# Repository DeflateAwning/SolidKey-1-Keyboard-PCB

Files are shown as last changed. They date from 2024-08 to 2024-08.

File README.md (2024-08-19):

# SolidKey-1-Keyboard-PCB
A capacitive touch QMK keyboard, with aspirations of replacing the Framework 13 keyboard

## Inspiration

* This project is inspired by [ebastler's UnMechanical Keyboard](https://github.com/ebastler/UnMechanical).

## Goals

* Make a columnar keyboard with a capacitive touch interface.
* Make the keyboard fit between the Framework 13 keyboard space and screen. Be compatible with the Framework 13 input cover's wiring.
* Base the locations of the keys on the Iris 6 keyboard.
* Parts:
    * RP2040 microcontroller
    * USB-C
    * Vibration motor
    * No LEDs!
* Low-ish power, low mass
* <$80 for a fully-assembled keyboard from JLCPCB

## Licence

The hardware component of this project is licenced under the `CERN Open Hardware Licence Version 2 - Weakly Reciprocal` licence. Variations must be shared under the same licence (or equivalent) licence. Commercial use is allowed, but the source must be shared, and it must be released/sold under a different name.

## Notes

* Framework 13 keyboard dimensions: 276.76mm x 105.0mm x 1.74mm, at the bottom of the taper up, based on their full STEP CAD model.
* For the 276mm x 105mm PCB from JLCPCB, it costs:
    * US$16.80 for 0.6mm thick, LeadFree HASL
    * US$60.60 for 0.4mm thick, requiring ENIG
    * US$10 shipping for these thin boards.
    * US$50 for 0.6mm assembly ("Standard"), but US$26 for 0.8mm assembly ("Economic").
    * 0.8mm weighs 54g each. 0.6mm weighs 40g-54g each.

## Resources

* RP2040 Design Guide: https://datasheets.raspberrypi.com/rp2040/hardware-design-with-rp2040.pdf
* CY8CMBR3116 Capacitive Touch Guides:
    * Datasheet: https://www.infineon.com/cms/en/product/microcontroller/sensing-controller/capsense-controllers/capsense-mbr3/cy8cmbr3116-lqxit/
    * CY8CMBR3xxx CapSense Design Guide: https://www.cypress.com/?rID=90800
    * Getting Started with CapSense: https://www.cypress.com/?rID=48787

## Future Work

* Add a dot mouse thing, like the ThinkPad keyboards.

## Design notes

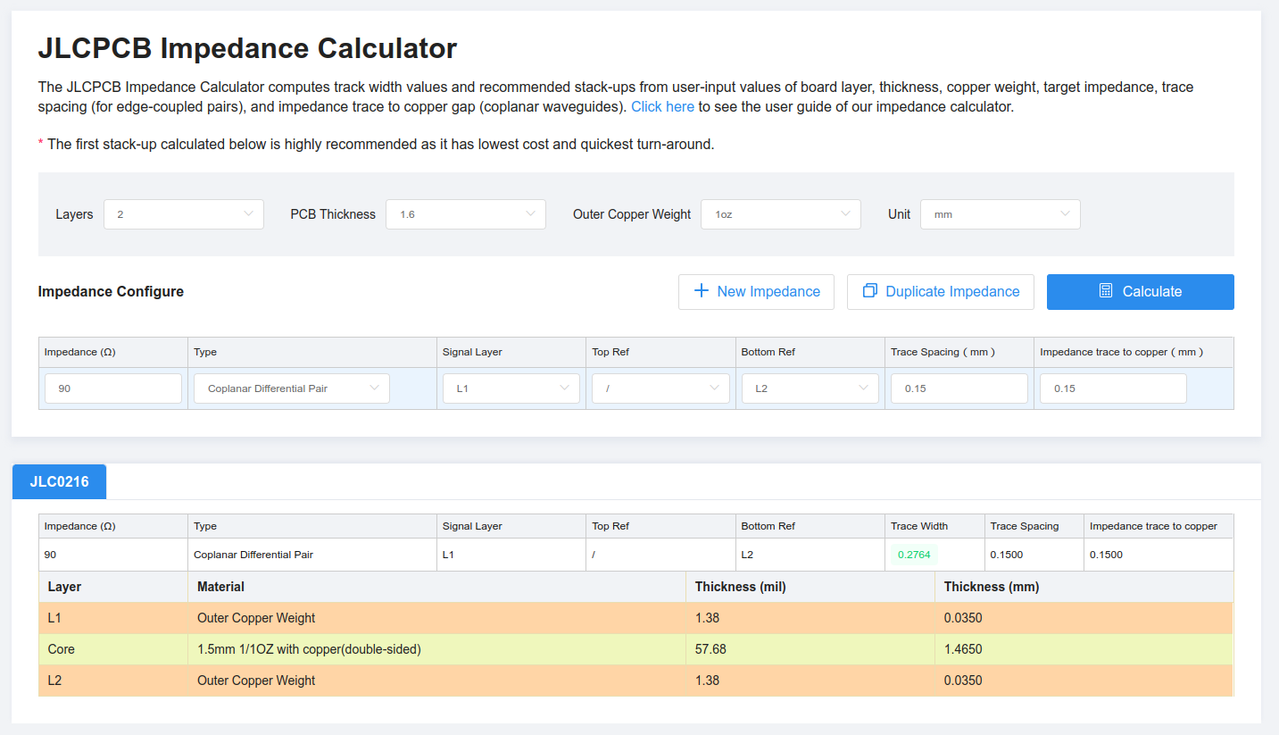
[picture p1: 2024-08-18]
docs/USB Trace Width Calculation - JLCPCB - 2 Layer, 0.15mm Spacing, 1.6mm PCB.png

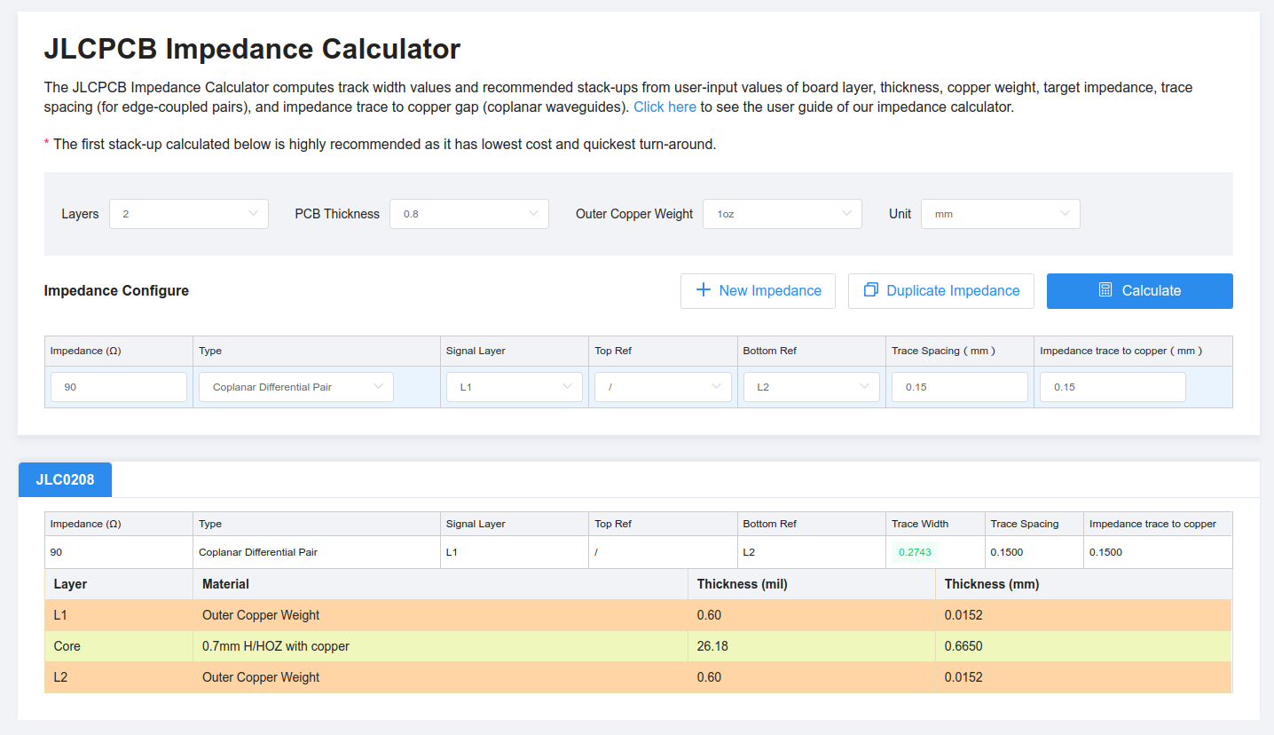
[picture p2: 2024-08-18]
docs/USB Trace Width Calculation - JLCPCB - 2 Layer, 0.15mm Spacing, 0.8mm PCB.png

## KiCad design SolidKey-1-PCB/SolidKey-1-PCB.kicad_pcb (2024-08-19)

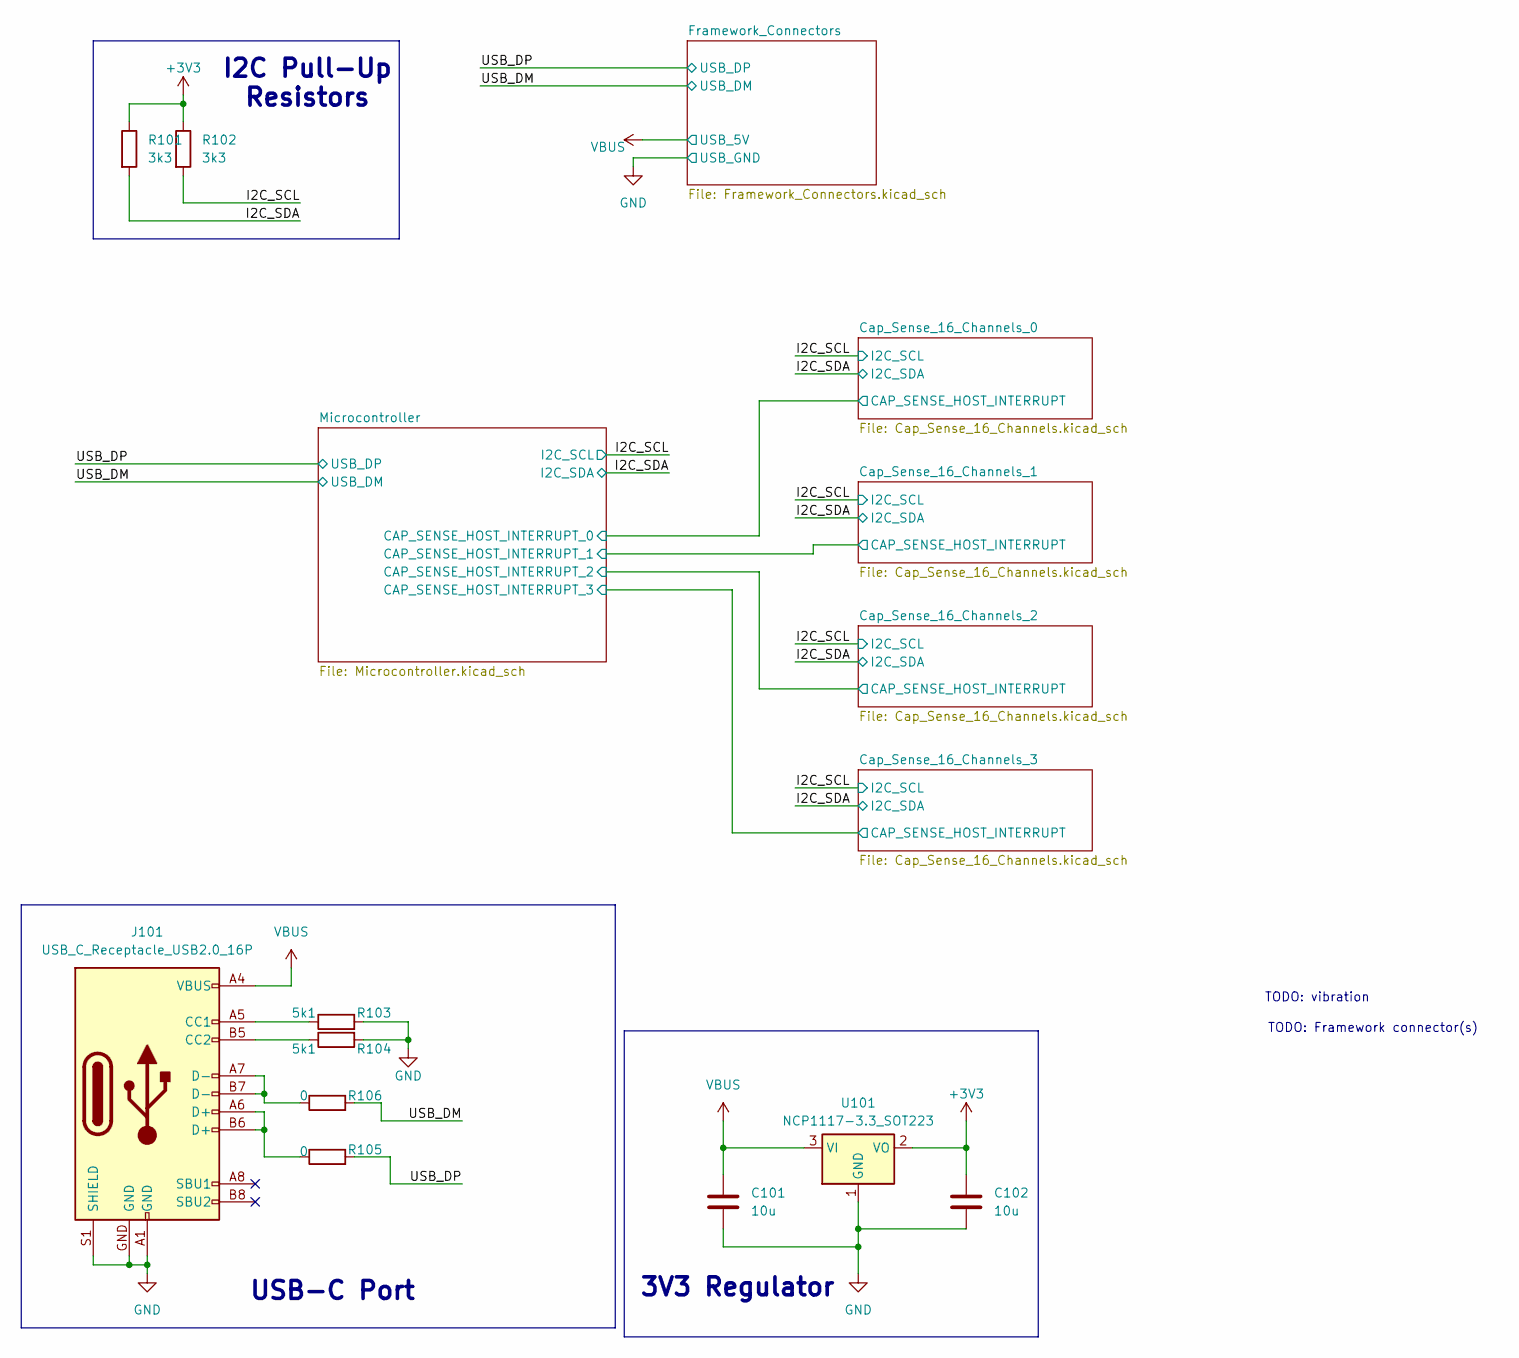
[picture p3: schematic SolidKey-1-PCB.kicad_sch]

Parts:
C101, C102: 10u; C_0402_1005Metric
J101: USB_C_Receptacle_USB2.0_16P; USB_C_Receptacle_G-Switch_GT-USB-7025
R101, R102: 3k3; R_0402_1005Metric
R103, R104: 5k1; R_0402_1005Metric
R105, R106: 0; R_0603_1608Metric
U101: NCP1117-3.3_SOT223; SOT-223-3_TabPin2

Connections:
+3V3: C102.1, R101.1, R102.1, U101.2 (VO); also elsewhere on the board
/I2C_SCL: R102.2; also elsewhere on the board
/I2C_SDA: R101.2; also elsewhere on the board
/USB_DM: R106.2; also elsewhere on the board
/USB_DP: R105.2; also elsewhere on the board
GND: C101.2, C102.2, J101.A1 (GND), J101.A12 (GND), J101.B1 (GND), J101.B12 (GND), J101.GND, J101.S1 (SHIELD), R103.2, R104.2, U101.1 (GND); also elsewhere on the board
unnamed: J101.A5 (CC1), R103.1
unnamed: J101.B5 (CC2), R104.1
unnamed: J101.A6 (D+), J101.B6 (D+), R105.1
unnamed: J101.A7 (D-), J101.B7 (D-), R106.1
VBUS: C101.1, J101.A4 (VBUS), J101.A9 (VBUS), J101.B4 (VBUS), J101.B9 (VBUS), U101.3 (VI); also elsewhere on the board

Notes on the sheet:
3V3 Regulator
I2C Pull-Up Resistors
TODO: Framework connector(s)
USB-C Port
TODO: vibration

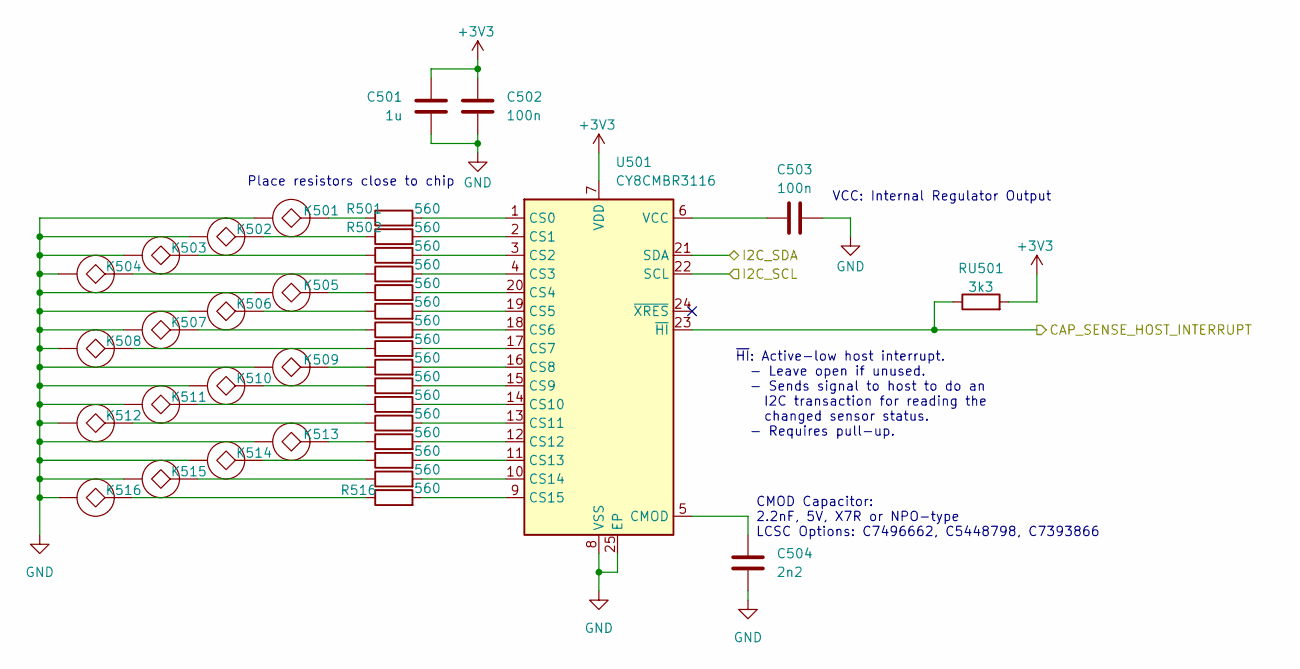
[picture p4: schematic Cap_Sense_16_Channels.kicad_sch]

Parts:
C501: 1u; C_0402_1005Metric
C502, C503: 100n; C_0402_1005Metric
C504: 2n2; C_0402_1005Metric; LCSC C7393866
K501, K502, K503, K504, K505, K506, K507, K508, K510, K511, K512, K514, K515, K516: TouchPoint; KeySwitch1_General
K509, K513: TouchPoint; KeySwitch1_Index
R501, R502, R503, R504, R505, R506, R507, R508, R509, R510, R511, R512, R513, R514, R515, R516: 560; R_0603_1608Metric
RU501: 3k3; R_0402_1005Metric
U501: CY8CMBR3116; QFN-24-1EP_4x4mm_P0.5mm_EP2.6x2.6mm

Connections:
+3V3: C501.1, C502.1, RU501.2, U501.7 (VDD); also elsewhere on the board
/Cap_Sense_16_Channels_2/CAP_SENSE_HOST_INTERRUPT: RU501.1, U501.23 (~HI); also elsewhere on the board
/I2C_SCL: U501.22 (SCL); also elsewhere on the board
/I2C_SDA: U501.21 (SDA); also elsewhere on the board
GND: C501.2, C502.2, C503.2, C504.2, K501.2 (GND), K502.2 (GND), K503.2 (GND), K504.2 (GND), K505.2 (GND), K506.2 (GND), K507.2 (GND), K508.2 (GND), K509.2 (GND), K510.2 (GND), K511.2 (GND), K512.2 (GND), K513.2 (GND), K514.2 (GND), K515.2 (GND), K516.2 (GND), U501.8 (VSS), U501.25 (EP); also elsewhere on the board
unnamed: K501.1, R501.1
unnamed: K502.1, R502.1
unnamed: K503.1, R503.1
unnamed: K504.1, R504.1
unnamed: K505.1, R505.1
unnamed: K506.1, R506.1
unnamed: K507.1, R507.1
unnamed: K508.1, R508.1
unnamed: K509.1, R509.1
unnamed: K510.1, R510.1
unnamed: K511.1, R511.1
unnamed: K512.1, R512.1
unnamed: K513.1, R513.1
unnamed: K514.1, R514.1
unnamed: K515.1, R515.1
unnamed: K516.1, R516.1
unnamed: C504.1, U501.5 (CMOD)
unnamed: R501.2, U501.1 (CS0)
unnamed: R502.2, U501.2 (CS1)
unnamed: R503.2, U501.3 (CS2)
unnamed: R504.2, U501.4 (CS3)
unnamed: R505.2, U501.20 (CS4)
unnamed: R506.2, U501.19 (CS5)
unnamed: R507.2, U501.18 (CS6)
unnamed: R508.2, U501.17 (CS7)
unnamed: R509.2, U501.16 (CS8)
unnamed: R510.2, U501.15 (CS9)
unnamed: R511.2, U501.14 (CS10)
unnamed: R512.2, U501.13 (CS11)
unnamed: R513.2, U501.12 (CS12)
unnamed: R514.2, U501.11 (CS13)
unnamed: R515.2, U501.10 (CS14)
unnamed: R516.2, U501.9 (CS15)
unnamed: C503.1, U501.6 (VCC)

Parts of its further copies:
C301, C401, C601: 1u; C_0402_1005Metric
C302, C303, C402, C403, C602, C603: 100n; C_0402_1005Metric
C304, C404, C604: 2n2; C_0402_1005Metric; LCSC C7393866
K301, K302, K303, K304, K305, K306, K307, K308, K310, K311, K312, K314, K315, K316, K401, K402, K403, K404, K405, K406, K407, K408, K410, K411, K412, K414, K415, K416, K601, K602, K603, K604, K605, K606, K607, K608, K610, K611, K612, K614, K615, K616: TouchPoint; KeySwitch1_General
K309, K313, K409, K413, K609, K613: TouchPoint; KeySwitch1_Index
R301, R302, R303, R304, R305, R306, R307, R308, R309, R310, R311, R312, R313, R314, R315, R316, R401, R402, R403, R404, R405, R406, R407, R408, R409, R410, R411, R412, R413, R414, R415, R416, R601, R602, R603, R604, R605, R606, R607, R608, R609, R610, R611, R612, R613, R614, R615, R616: 560; R_0603_1608Metric
RU301, RU401, RU601: 3k3; R_0402_1005Metric
U301, U401, U601: CY8CMBR3116; QFN-24-1EP_4x4mm_P0.5mm_EP2.6x2.6mm

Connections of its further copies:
+3V3: C301.1, C302.1, C401.1, C402.1, C601.1, C602.1, RU301.2, RU401.2, RU601.2, U301.7 (VDD), U401.7 (VDD), U601.7 (VDD); also elsewhere on the board
/Cap_Sense_16_Channels_0/CAP_SENSE_HOST_INTERRUPT: RU301.1, U301.23 (~HI); also elsewhere on the board
/Cap_Sense_16_Channels_1/CAP_SENSE_HOST_INTERRUPT: RU401.1, U401.23 (~HI); also elsewhere on the board
/Cap_Sense_16_Channels_3/CAP_SENSE_HOST_INTERRUPT: RU601.1, U601.23 (~HI); also elsewhere on the board
/I2C_SCL: U301.22 (SCL), U401.22 (SCL), U601.22 (SCL); also elsewhere on the board
/I2C_SDA: U301.21 (SDA), U401.21 (SDA), U601.21 (SDA); also elsewhere on the board
GND: C301.2, C302.2, C303.2, C304.2, C401.2, C402.2, C403.2, C404.2, C601.2, C602.2, C603.2, C604.2, K301.2 (GND), K302.2 (GND), K303.2 (GND), K304.2 (GND), K305.2 (GND), K306.2 (GND), K307.2 (GND), K308.2 (GND), K309.2 (GND), K310.2 (GND), K311.2 (GND), K312.2 (GND), K313.2 (GND), K314.2 (GND), K315.2 (GND), K316.2 (GND), K401.2 (GND), K402.2 (GND), K403.2 (GND), K404.2 (GND), K405.2 (GND), K406.2 (GND), K407.2 (GND), K408.2 (GND), K409.2 (GND), K410.2 (GND), K411.2 (GND), K412.2 (GND), K413.2 (GND), K414.2 (GND), K415.2 (GND), K416.2 (GND), K601.2 (GND), K602.2 (GND), K603.2 (GND), K604.2 (GND), K605.2 (GND), K606.2 (GND), K607.2 (GND), K608.2 (GND), K609.2 (GND), K610.2 (GND), K611.2 (GND), K612.2 (GND), K613.2 (GND), K614.2 (GND), K615.2 (GND), K616.2 (GND), U301.8 (VSS), U301.25 (EP), U401.8 (VSS), U401.25 (EP), U601.8 (VSS), U601.25 (EP); also elsewhere on the board
unnamed: K301.1, R301.1
unnamed: K302.1, R302.1
unnamed: K303.1, R303.1
unnamed: K304.1, R304.1
unnamed: K305.1, R305.1
unnamed: K306.1, R306.1
unnamed: K307.1, R307.1
unnamed: K308.1, R308.1
unnamed: K309.1, R309.1
unnamed: K310.1, R310.1
unnamed: K311.1, R311.1
unnamed: K312.1, R312.1
unnamed: K313.1, R313.1
unnamed: K314.1, R314.1
unnamed: K315.1, R315.1
unnamed: K316.1, R316.1
unnamed: K401.1, R401.1
unnamed: K402.1, R402.1
unnamed: K403.1, R403.1
unnamed: K404.1, R404.1
unnamed: K405.1, R405.1
unnamed: K406.1, R406.1
unnamed: K407.1, R407.1
unnamed: K408.1, R408.1
unnamed: K409.1, R409.1
unnamed: K410.1, R410.1
unnamed: K411.1, R411.1
unnamed: K412.1, R412.1
unnamed: K413.1, R413.1
unnamed: K414.1, R414.1
unnamed: K415.1, R415.1
unnamed: K416.1, R416.1
unnamed: K601.1, R601.1
unnamed: K602.1, R602.1
unnamed: K603.1, R603.1
unnamed: K604.1, R604.1
unnamed: K605.1, R605.1
unnamed: K606.1, R606.1
unnamed: K607.1, R607.1
unnamed: K608.1, R608.1
unnamed: K609.1, R609.1
unnamed: K610.1, R610.1
unnamed: K611.1, R611.1
unnamed: K612.1, R612.1
unnamed: K613.1, R613.1
unnamed: K614.1, R614.1
unnamed: K615.1, R615.1
unnamed: K616.1, R616.1
unnamed: C304.1, U301.5 (CMOD)
unnamed: R301.2, U301.1 (CS0)
unnamed: R302.2, U301.2 (CS1)
unnamed: R303.2, U301.3 (CS2)
unnamed: R304.2, U301.4 (CS3)
unnamed: R305.2, U301.20 (CS4)
unnamed: R306.2, U301.19 (CS5)
unnamed: R307.2, U301.18 (CS6)
unnamed: R308.2, U301.17 (CS7)
unnamed: R309.2, U301.16 (CS8)
unnamed: R310.2, U301.15 (CS9)
unnamed: R311.2, U301.14 (CS10)
unnamed: R312.2, U301.13 (CS11)
unnamed: R313.2, U301.12 (CS12)
unnamed: R314.2, U301.11 (CS13)
unnamed: R315.2, U301.10 (CS14)
unnamed: R316.2, U301.9 (CS15)
unnamed: C303.1, U301.6 (VCC)
unnamed: C404.1, U401.5 (CMOD)
unnamed: R401.2, U401.1 (CS0)
unnamed: R402.2, U401.2 (CS1)
unnamed: R403.2, U401.3 (CS2)
unnamed: R404.2, U401.4 (CS3)
unnamed: R405.2, U401.20 (CS4)
unnamed: R406.2, U401.19 (CS5)
unnamed: R407.2, U401.18 (CS6)
unnamed: R408.2, U401.17 (CS7)
unnamed: R409.2, U401.16 (CS8)
unnamed: R410.2, U401.15 (CS9)
unnamed: R411.2, U401.14 (CS10)
unnamed: R412.2, U401.13 (CS11)
unnamed: R413.2, U401.12 (CS12)
unnamed: R414.2, U401.11 (CS13)
unnamed: R415.2, U401.10 (CS14)
unnamed: R416.2, U401.9 (CS15)
unnamed: C403.1, U401.6 (VCC)
unnamed: C604.1, U601.5 (CMOD)
unnamed: R601.2, U601.1 (CS0)
unnamed: R602.2, U601.2 (CS1)
unnamed: R603.2, U601.3 (CS2)
unnamed: R604.2, U601.4 (CS3)
unnamed: R605.2, U601.20 (CS4)
unnamed: R606.2, U601.19 (CS5)
unnamed: R607.2, U601.18 (CS6)
unnamed: R608.2, U601.17 (CS7)
unnamed: R609.2, U601.16 (CS8)
unnamed: R610.2, U601.15 (CS9)
unnamed: R611.2, U601.14 (CS10)
unnamed: R612.2, U601.13 (CS11)
unnamed: R613.2, U601.12 (CS12)
unnamed: R614.2, U601.11 (CS13)
unnamed: R615.2, U601.10 (CS14)
unnamed: R616.2, U601.9 (CS15)
unnamed: C603.1, U601.6 (VCC)

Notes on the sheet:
CMOD Capacitor: 2.2nF, 5V, X7R or NPO-type LCSC Options: C7496662, C5448798, C7393866
~{HI}: Active-low host interrupt. - Leave open if unused. - Sends signal to host to do an I2C transaction for reading the changed sensor status. - Requires pull-up.
Place resistors close to chip
VCC: Internal Regulator Output

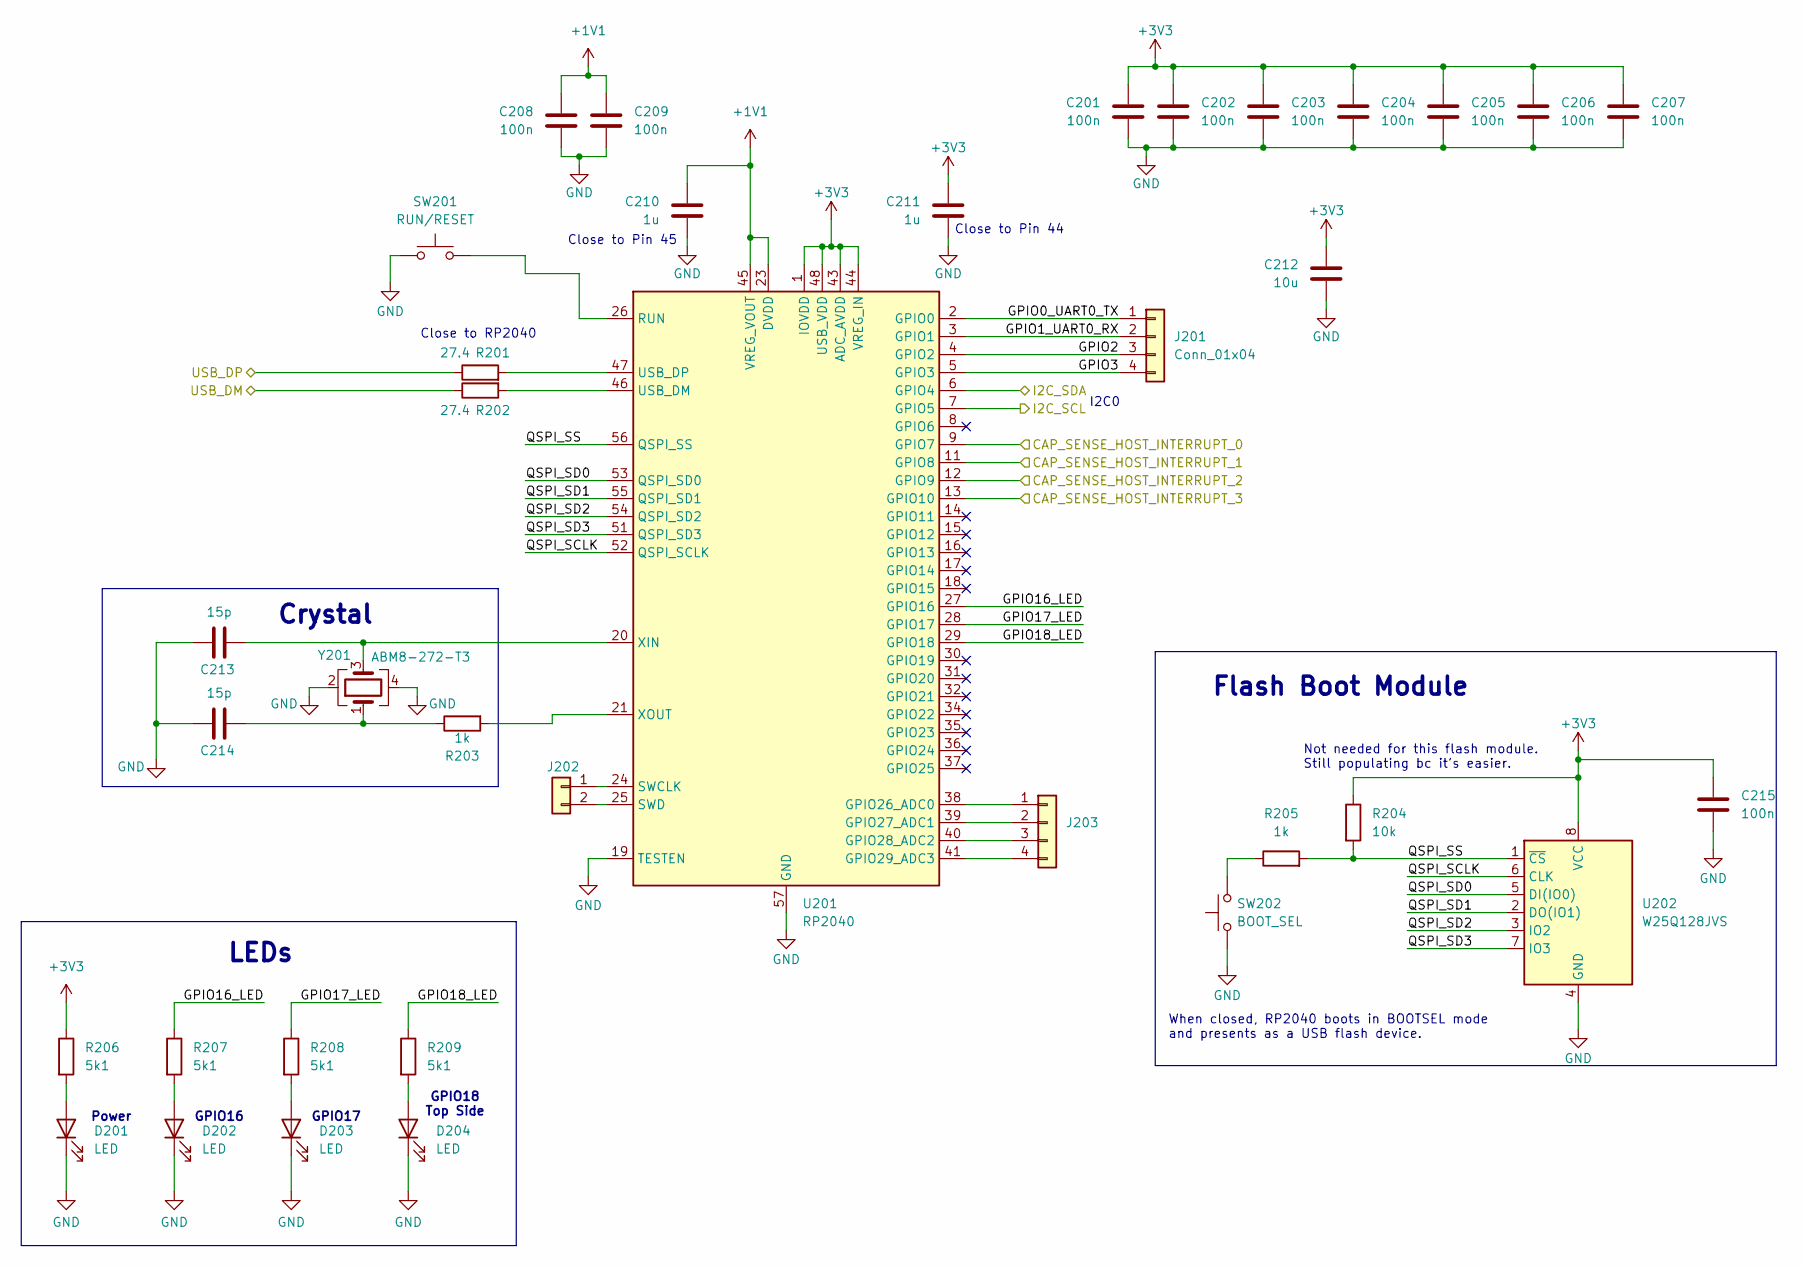
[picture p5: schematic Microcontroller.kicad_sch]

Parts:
C201, C202, C203, C204, C205, C206, C207, C208, C209, C215: 100n; C_0402_1005Metric
C210, C211: 1u; C_0402_1005Metric
C212: 10u; C_0402_1005Metric
C213, C214: 15p; C_0402_1005Metric
D201, D202, D203, D204: LED; LED_0603_1608Metric
J201, J203: Conn_01x04; PinHeader_1x04_P2.54mm_Vertical_SMD_Pin1Left
J202: Conn_01x02; PinHeader_1x02_P2.54mm_Vertical_SMD_Pin1Left
R201, R202: 27.4; R_0402_1005Metric
R203, R205: 1k; R_0402_1005Metric
R204: 10k; R_0402_1005Metric
R206, R207, R208, R209: 5k1; R_0402_1005Metric
SW201: RUN/RESET; SW_Push_1P1T_XKB_TS-1187A; LCSC C318884
SW202: BOOT_SEL; SW_Push_1P1T_XKB_TS-1187A; LCSC C318884
U201: RP2040; QFN-56-1EP_7x7mm_P0.4mm_EP3.2x3.2mm
U202: W25Q128JVS; SOIC-8_5.23x5.23mm_P1.27mm; LCSC C97521
Y201: ABM8-272-T3; Crystal_SMD_3225-4Pin_3.2x2.5mm; LCSC C20625731

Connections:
+1V1: C208.1, C209.1, C210.1, U201.23 (DVDD), U201.45 (VREG_VOUT), U201.50 (DVDD)
+3V3: C201.1, C202.1, C203.1, C204.1, C205.1, C206.1, C207.1, C211.1, C212.1, C215.1, R204.1, R206.1, U201.1 (IOVDD), U201.10 (IOVDD), U201.22 (IOVDD), U201.33 (IOVDD), U201.42 (IOVDD), U201.43 (ADC_AVDD), U201.44 (VREG_IN), U201.48 (USB_VDD), U201.49 (IOVDD), U202.8 (VCC); also elsewhere on the board
/Cap_Sense_16_Channels_0/CAP_SENSE_HOST_INTERRUPT: U201.9 (GPIO7); also elsewhere on the board
/Cap_Sense_16_Channels_1/CAP_SENSE_HOST_INTERRUPT: U201.11 (GPIO8); also elsewhere on the board
/Cap_Sense_16_Channels_2/CAP_SENSE_HOST_INTERRUPT: U201.12 (GPIO9); also elsewhere on the board
/Cap_Sense_16_Channels_3/CAP_SENSE_HOST_INTERRUPT: U201.13 (GPIO10); also elsewhere on the board
/I2C_SCL: U201.7 (GPIO5); also elsewhere on the board
/I2C_SDA: U201.6 (GPIO4); also elsewhere on the board
/Microcontroller/GPIO0_UART0_TX: J201.1, U201.2 (GPIO0)
/Microcontroller/GPIO1_UART0_RX: J201.2, U201.3 (GPIO1)
/Microcontroller/GPIO2: J201.3, U201.4 (GPIO2)
/Microcontroller/GPIO3: J201.4, U201.5 (GPIO3)
/Microcontroller/GPIO16_LED: R207.1, U201.27 (GPIO16)
/Microcontroller/GPIO17_LED: R208.1, U201.28 (GPIO17)
/Microcontroller/GPIO18_LED: R209.1, U201.29 (GPIO18)
/Microcontroller/QSPI_SCLK: U201.52 (QSPI_SCLK), U202.6 (CLK)
/Microcontroller/QSPI_SD0: U201.53 (QSPI_SD0), U202.5 (DI(IO0))
/Microcontroller/QSPI_SD1: U201.55 (QSPI_SD1), U202.2 (DO(IO1))
/Microcontroller/QSPI_SD2: U201.54 (QSPI_SD2), U202.3 (IO2)
/Microcontroller/QSPI_SD3: U201.51 (QSPI_SD3), U202.7 (IO3)
/Microcontroller/QSPI_SS: R204.2, R205.2, U201.56 (QSPI_SS), U202.1 (~CS)
/USB_DM: R202.1; also elsewhere on the board
/USB_DP: R201.1; also elsewhere on the board
GND: C201.2, C202.2, C203.2, C204.2, C205.2, C206.2, C207.2, C208.2, C209.2, C210.2, C211.2, C212.2, C213.1, C214.1, C215.2, D201.1 (K), D202.1 (K), D203.1 (K), D204.1 (K), SW201.1, SW202.1, U201.19 (TESTEN), U201.57 (GND), U202.4 (GND), Y201.2, Y201.4; also elsewhere on the board
unnamed: C214.2, R203.1, Y201.1
unnamed: D201.2 (A), R206.2
unnamed: D202.2 (A), R207.2
unnamed: D203.2 (A), R208.2
unnamed: D204.2 (A), R209.2
unnamed: J202.1, U201.24 (SWCLK)
unnamed: J202.2, U201.25 (SWD)
unnamed: J203.1, U201.38 (GPIO26_ADC0)
unnamed: J203.2, U201.39 (GPIO27_ADC1)
unnamed: J203.3, U201.40 (GPIO28_ADC2)
unnamed: J203.4, U201.41 (GPIO29_ADC3)
unnamed: R205.1, SW202.2
unnamed: SW201.2, U201.26 (RUN)
unnamed: R202.2, U201.46 (USB_DM)
unnamed: R201.2, U201.47 (USB_DP)
unnamed: C213.2, U201.20 (XIN), Y201.3
unnamed: R203.2, U201.21 (XOUT)

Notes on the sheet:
GPIO16
When closed, RP2040 boots in BOOTSEL mode and presents as a USB flash device.
Close to RP2040
GPIO17
Flash Boot Module
Power
LEDs
Not needed for this flash module. Still populating bc it's easier.
GPIO18 Top Side
Crystal
Close to Pin 45
I2C0
Close to Pin 44

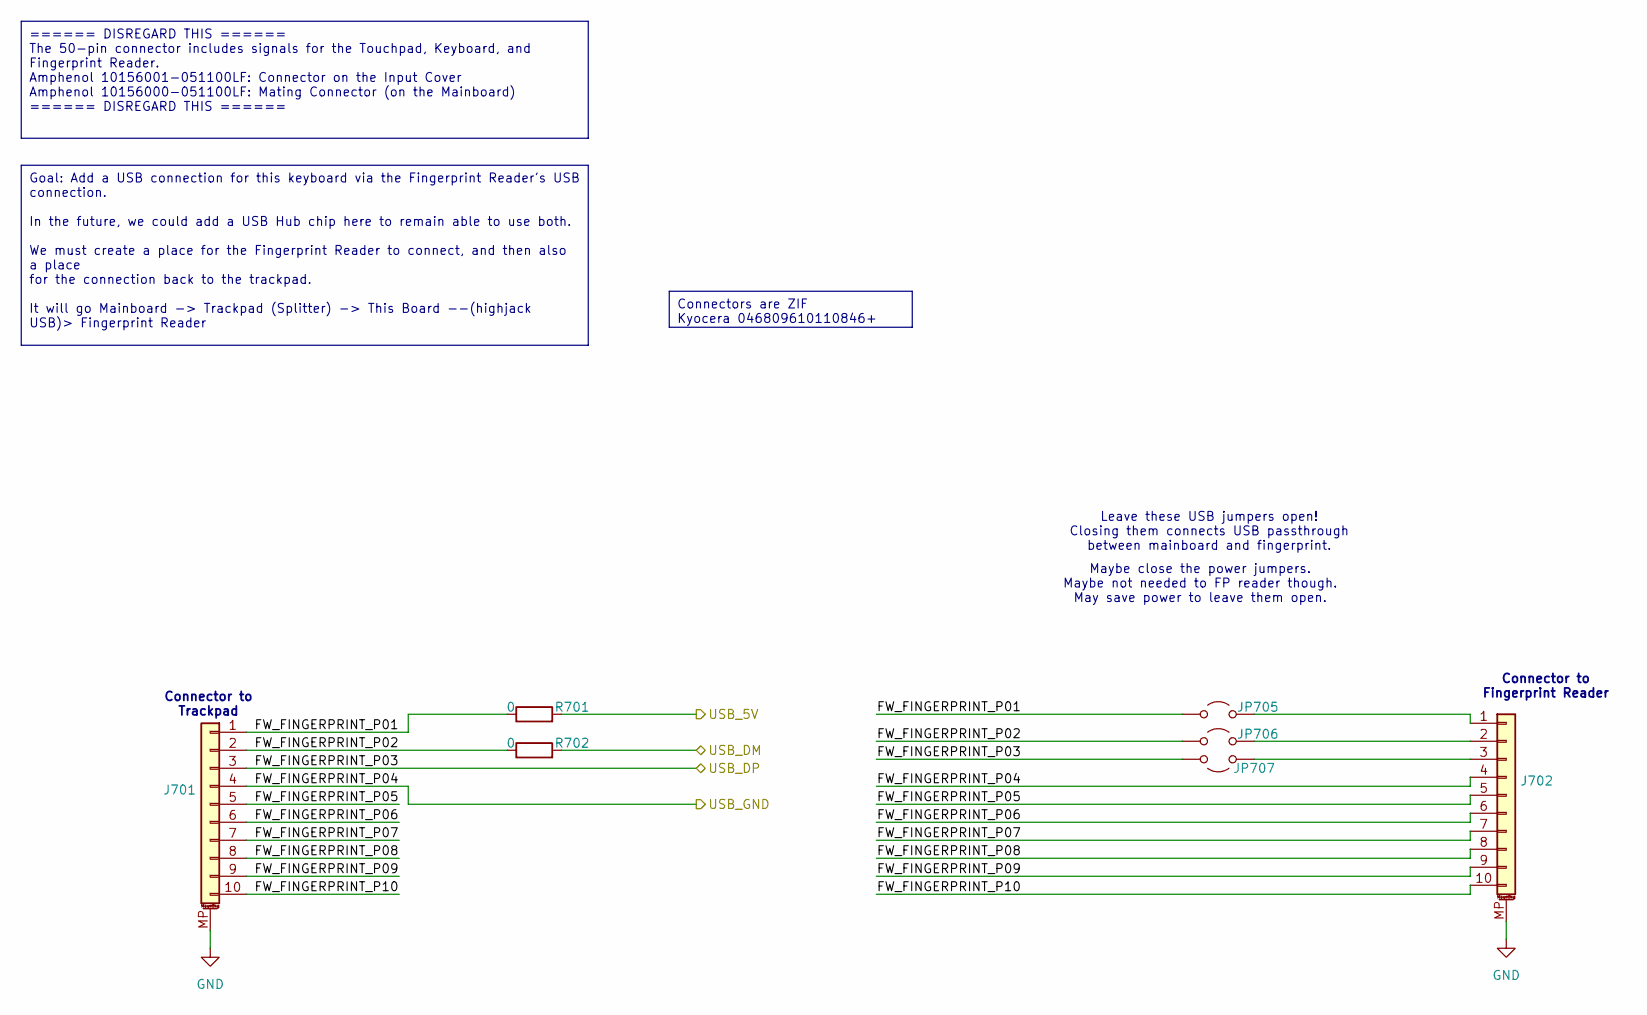
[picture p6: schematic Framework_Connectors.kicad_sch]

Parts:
J701, J702: Conn_01x10_MountingPin; 046809610110846
JP705, JP706, JP707: Jumper_2_Open; SolderJumper-2_P1.3mm_Open_XSilk_RoundedPad1.0x1.5mm
R701, R702: 0; R_0603_1608Metric

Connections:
/Framework_Connectors/FW_FINGERPRINT_P01: J701.1, JP705.2 (B), R701.1
/Framework_Connectors/FW_FINGERPRINT_P02: J701.2, JP706.2 (B), R702.1
/Framework_Connectors/FW_FINGERPRINT_P05: J701.5, J702.5
/Framework_Connectors/FW_FINGERPRINT_P06: J701.6, J702.6
/Framework_Connectors/FW_FINGERPRINT_P07: J701.7, J702.7
/Framework_Connectors/FW_FINGERPRINT_P08: J701.8, J702.8
/Framework_Connectors/FW_FINGERPRINT_P09: J701.9, J702.9
/Framework_Connectors/FW_FINGERPRINT_P10: J701.10, J702.10
/USB_DM: R702.2; also elsewhere on the board
/USB_DP: J701.3, JP707.2 (B); also elsewhere on the board
GND: J701.4, J701.MP (MountPin), J702.4, J702.MP (MountPin); also elsewhere on the board
unnamed: J702.1, JP705.1 (A)
unnamed: J702.2, JP706.1 (A)
unnamed: J702.3, JP707.1 (A)
VBUS: R701.2; also elsewhere on the board

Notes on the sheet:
Goal: Add a USB connection for this keyboard via the Fingerprint Reader's USB connection. In the future, we could add a USB Hub chip here to remain able to use both. We must create a place for the Fingerprint Reader to connect, and then also a place for the connection back to the trackpad. It will 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
====== DISREGARD THIS ====== The 50-pin connector includes signals for the Touchpad, Keyboard, and Fingerprint Reader. Amphenol 10156001-051100LF: Connector on the Input Cover Amphenol 10156000-051100LF: Mating Connector (on the Mainboard) ====== DISREGARD THIS ======
Connectors are ZIF Kyocera 046809610110846+
Maybe close the power jumpers. Maybe not needed to FP reader though. May save power to leave them open.
Leave these USB jumpers open! Closing them connects USB passthrough between mainboard and fingerprint.
Connector to Trackpad
Connector to Fingerprint Reader

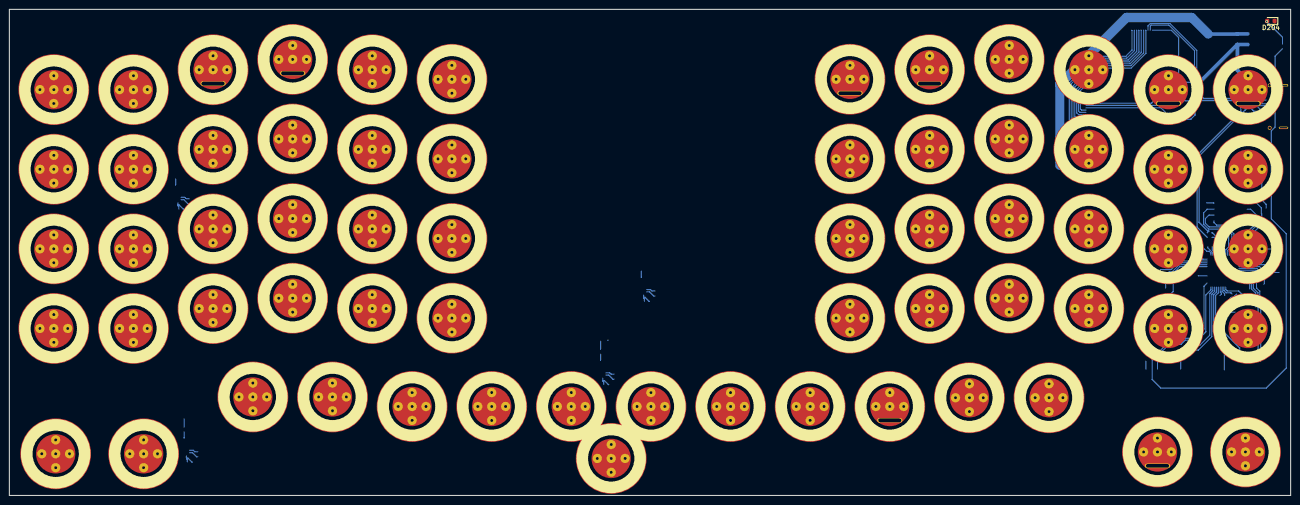
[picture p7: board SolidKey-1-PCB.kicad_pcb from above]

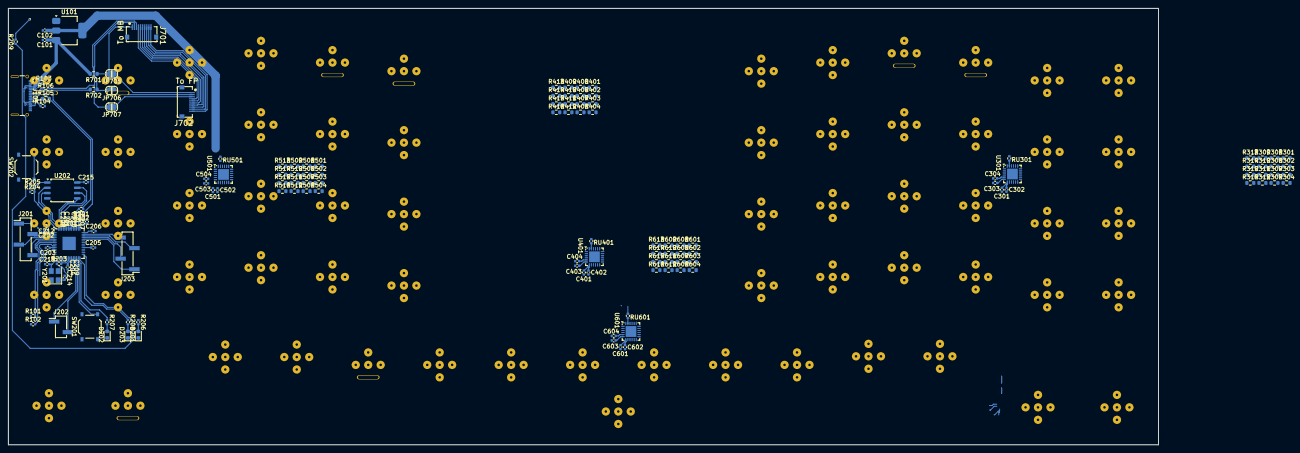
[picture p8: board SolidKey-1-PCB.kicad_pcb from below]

Board: 2 copper layers, 276.8 x 105.0 mm, 205 parts (140 on the bottom side), 193 nets.

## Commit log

2024-08-18 Design the keyboard, mostly
    [Cap_Sense_16_Channels.kicad_sch, Framework_Connectors.kicad_sch, Microcontroller.kicad_sch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]
2024-08-18 Add Framwork connectors and start routing
    [Cap_Sense_16_Channels.kicad_sch, Framework_Connectors.kicad_sch, Microcontroller.kicad_sch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]
2024-08-18 Place each capacitive sensor chip block
    [SolidKey-1-PCB.kicad_pcb]
2024-08-19 Import final iris layout to PCB
    [SolidKey-1-PCB.kicad_pcb]
2024-08-19 Prepare to place the keys
    [SolidKey-1-PCB.kicad_pcb]
2024-08-19 Finish key layout placement
    [SolidKey-1-PCB.kicad_pcb]
2024-08-19 Reposition CapSense chips
    [Cap_Sense_16_Channels.kicad_sch, SolidKey-1-PCB.kicad_pcb]
